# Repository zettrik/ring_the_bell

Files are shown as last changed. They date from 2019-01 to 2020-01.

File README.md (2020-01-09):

# ring_the_bell
*speedy bees*

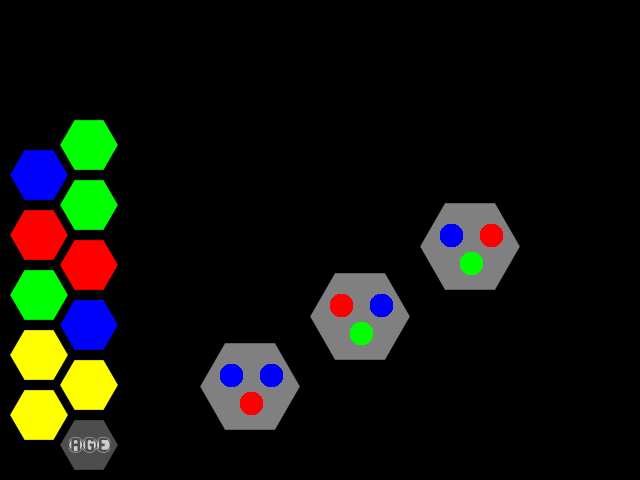
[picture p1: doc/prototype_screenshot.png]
Screenshot Prototype


## Game Principle

### Rules Of "Climb The Ladder"

The goal of this game is to climb the ladder and ring the bell. But
you won't climb alone. You have to be fast as a team.

The "ladder" has ten random blinking lights. Every player has a gamepad with three
blinking buttons. They also change the color at random. In one moment a color will
settle on the ladder as one the gamepads. Press as fast as you can all buttons 
with same color. All of you have to do is hit the right button just in time to 
climb one step up.

If one of you ist too slow, the next round will start at the same level.
If one of you hits a wrong button, you fall one step down.

Start of the game will be easy and you will climp up quickly. As you raise level
your time will shorten. Also some unforseen things might happen at any time.

Will you reach the top and ring the bell?

## User Guide

The Game is a proof of concept and fun project. One focus was to document small
details. Have fun while building it or a similar game.

* [Gamecontrolmaster](/doc/Gamecontrolmaster.md)
* [Display (RGB Lights or Projector)](/doc/Display.md)
* [Gamepads](doc/Gamepads.md)

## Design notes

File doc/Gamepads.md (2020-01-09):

# Gamepads

The Gamepads are self made and consist of a wifi enabled microcontroller (esp32), three buttons and three rgb LEDs. Adopt the .ino firmware file to your needs (like wifi password, IP addresses, etc.) and flash it to the esp32.

* gamepad.ino
  * connects to wifi AP
  * recieves time from local ntp server
  * recieves commands from gamecontrolmaster
    * game states
    * ntp resync
  * animates button colors
  * sends button states to master

Remember you have to recompile the firmware and flash it again on all gamepads after making
changes to your wifi/network setup.

## Gamepad Schematics

Setup: BMS :left_right_arrow: 2x Li-Ion battery 4.2V :left_right_arrow: 5V step up :left_right_arrow: ESP32 dev board :left_right_arrow: 3.3V buttons & LEDs

Wiring of batteries, buttons and LEDs to the ESP32:

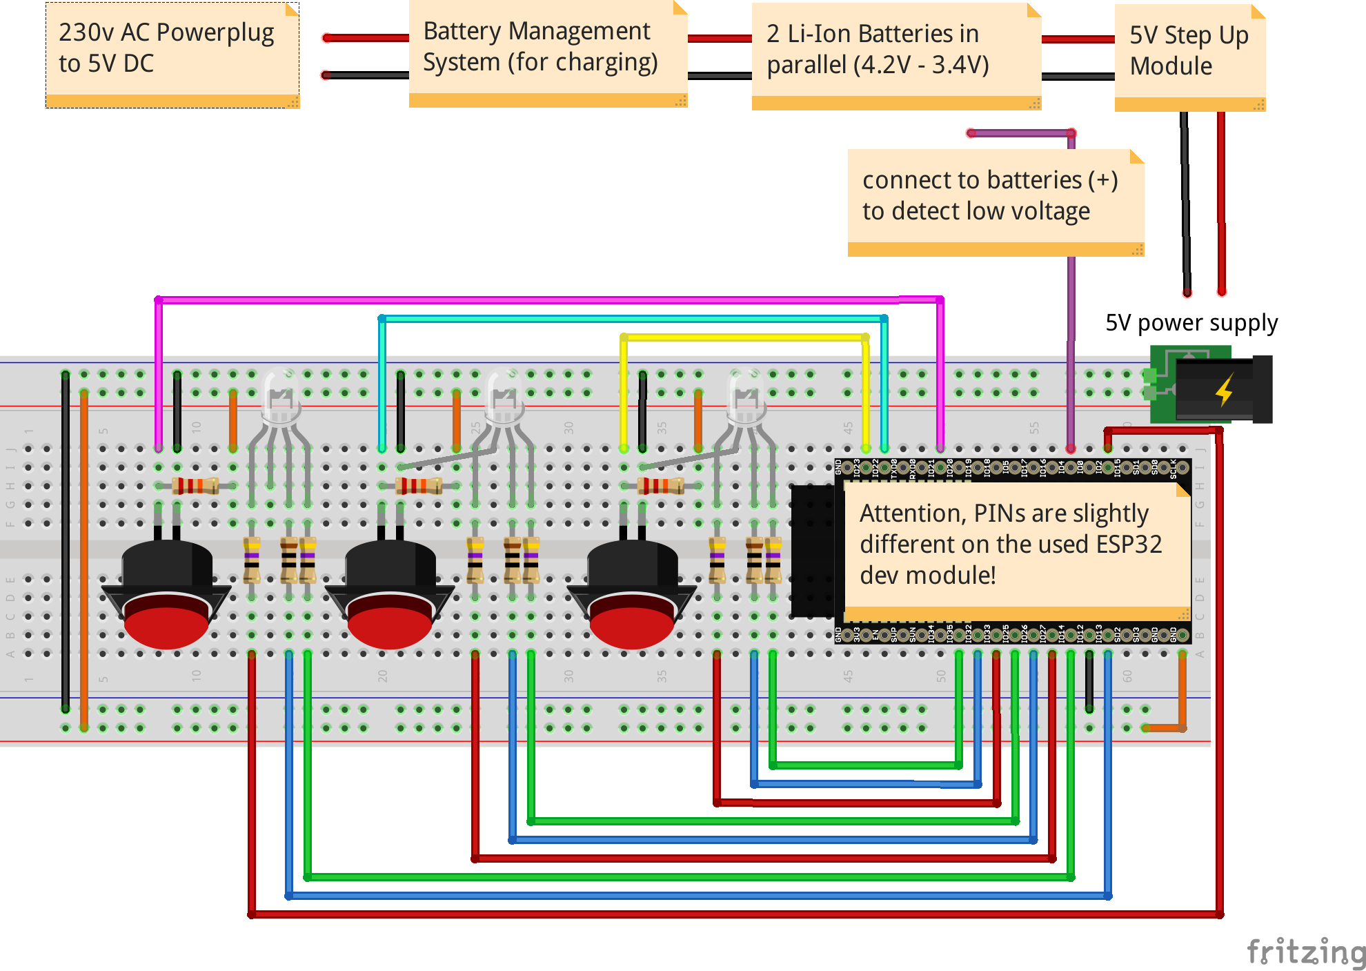
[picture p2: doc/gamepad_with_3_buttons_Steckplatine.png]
gamepad, buttons, leds


Two batteries are used in parallel with 2.200mAh each. The Gamepad uses between 70mA and 200mA. So you should be able to play at least 24h. 8) 
It will blink red and poweroff if battery voltage is below 3.4V. Recharge via USB, powerplug or change the cells. You find many of them in old notebook batteries.

ESP32 Pinmap:

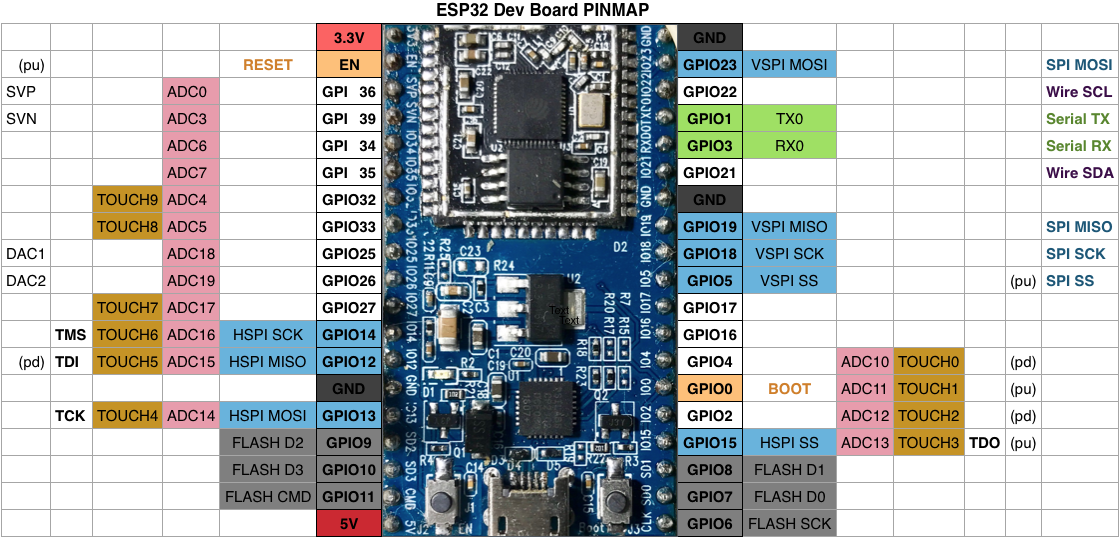
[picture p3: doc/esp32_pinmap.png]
ESP32 Pinmap


* [ESP32 Pin Reference](https://randomnerdtutorials.com/esp32-pinout-reference-gpios/)
* [ESP32 wroom Fritzing part](https://github.com/troelssiggaard/ESP32-fritzing-module)

## Flashing the Firmware

Easiest way of flashing is by using the Arduino IDE. Enhance it with the software from
espressif to flash esp32 boards.

* Install the current upstream Arduino IDE at the 1.8 level or later. The current version is at the [Arduino website](http://www.arduino.cc/en/main/software).
* Start Arduino and open Preferences window.
* Enter ```https://dl.espressif.com/dl/package_esp32_index.json``` into *Additional Board Manager URLs* field. You can add multiple URLs, separating them with commas.
* Open Boards Manager from Tools > Board menu and install *esp32* platform.
* Select your ESP32 board from Tools > Board menu after installation (in our case "NodeMCU-32S").

* [Espressif Esp32 @ github](https://github.com/espressif/arduino-esp32)

## Gamepad States

To lower complexity the gamepad software is written as a state machine. See
https://www.norwegiancreations.com/2017/03/state-machines-and-arduino-implementation/
for a quick introduction.

* states:
  * [1] random blinking
  * [2] freeze
  * [3] send udp packet
  * [4] recieve udp packet
  * [5] blink buttons pressed right in time
  * [6] sync time
* inputs:
  * udp packets
* outputs:
  * LEDs
  * udp packets

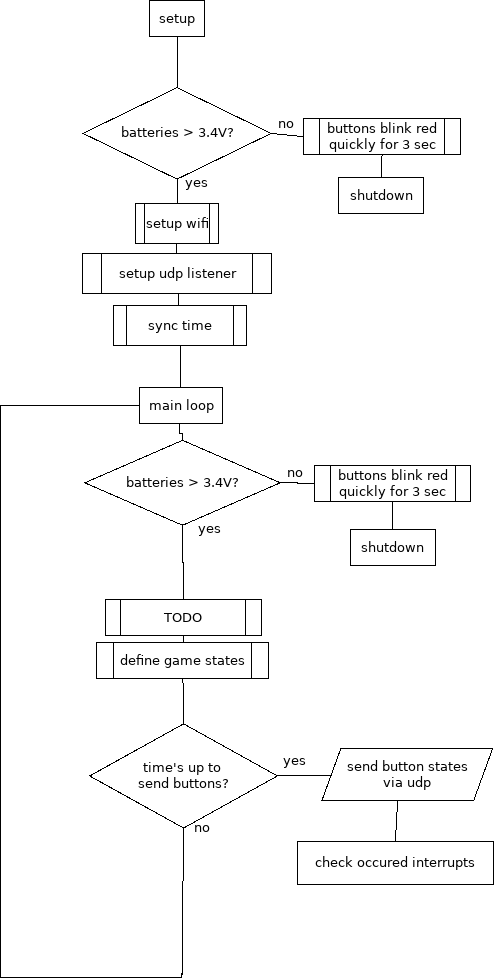
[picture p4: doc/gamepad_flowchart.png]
Gamepad flowchart


### UDP Packets
* timestamp, button1, color, dt, button2, color, dt, button3, color, dt
 * dt means after how many ms button was last pressed in this second
 * e.g.: "1546727493, 1,1,0, 2,3,427, 3,1,755"
* debug with any linux computer in the same wifi with: `sudo tcpdump -vvv -l -n port 3333`
* modus can be:
  * 0: nothing
  * 1: Helo
  * 2: Freeze
  * 3: Release
  * 4: NTP resync
  * 5: Animation1
  * 6: Animation2

## Open Hardware Power Supply
There are plenty of cheap commercial modules available. One is used for the prototype. You could go the full open hardware path by replacing them. Here are some ideas:

* li-ion battery management system
  * https://easyeda.com/search?wd=li-ion%20bms
  * https://github.com/stuartpittaway/diyBMS
  * https://secondlifestorage.com/index.php
  * https://www.youtube.com/watch?v=OdH3wYeFJ3M
  * https://foxbms.org
  * https://github.com/Teslafly/OpenBMS

* 5V step up boost module
  * https://chioszrobots.com/2013/10/11/dc-dc-1a-3v-to-5v-converter-step-up-boost-module/
  * https://easyeda.com/oshw/Arduino_Pro_Mini_328_5V_16MHz_Open_hardware-PuigQOLlx

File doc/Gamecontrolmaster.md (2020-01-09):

# Gamecontrolmaster

## Pyglet Prototype

There is a software prototype of the game for easier development, testing
the rules and joy of gameplay.

Screenshot Prototype

It uses pyglet as game engine. Most software the protoype depends on is in the
Debian Linux distribution. The newest version of pyglet comes via pip. Install
with the following commands.
```
cd prototype
apt install python3-pip freeglut3-dev python3-serial
pip3 install -r requirements.txt
python3 prototype.py
```

### Start on Boot
* create /lib/systemd/system/prototype.service with:
```
[Unit]
Description=Prototype
After=multi-user.target

[Service]
WorkingDirectory=/home/pi/ring_the_bell/prototype/
ExecStart=/usr/bin/python3 prototype.py

[Install]
WantedBy=multi-user.target
```
* chmod 644 /lib/systemd/system/prototype.service
* systemctl daemon-reload
* systemctl enable prototype.service

### Keybindings (Pre State Machine)

There is only a limited number of differnent states in the game. Test them in
the prototype with the letters in the brackets.
* [s] start
* [t] request gamepads to resync their time (ntp)
* [r] random blinking
* [f] freeze, wait for reactions
* [e] release
* [u] level up
* [d] level down
* [w] win
* [q] quit

## Raspberry Pi With Raspbian (Debian Stretch)

* Install [Raspbian](https://www.raspberrypi.org/downloads/raspbian/)
* You will need these essential Debian packages for gamecontrolmaster:
  * `python3 ntp`
  * Also install python3 from requirements.txt.
* There is no standalone mode yet. Use the gamemaster headless via ssh, in addition with the following handy packages:
  * `git` - to get the software
  * `screen` - for disruptable ssh sessions
  * `htop` - resource monitoring
  * `mc` - commandline file manager
  * `tcpdump` - debug network traffic
  * `vim` - file editor
* For all features install a dekstop like fluxbox
  * `lightdm fluxbox lxterminal bbrun`

## Components

### Wifi In AP Mode

* [Raspberry Pi help on this](https://www.raspberrypi.org/documentation/configuration/wireless/access-point.md)
* name: "speedybees"
* password: "rockyoursocksoff"
* IP address: 172.16.2.2
* or set up a separate access point instead of the onboard chip
  * switch wifi to client mode on Pi
  * leave IP address of Rapsberry Pi: 172.16.2.2
  * set IP address of access point: 172.16.2.1
  * use same wifi name + credentials or recompile firmware for gamepads
  * enable DHCP server on access point for address range: 172.16.2.3 - 172.16.2.254
  * no internet connection or DNS is needed but it will nat an existing one

### NTP

* ntp server - add this line to /etc/ntp.conf:
  * restrict 172.16.2.0 mask 255.255.255.0 nomodify notrap

### Firewall

* open firewall ports:
  * 123 for ntp
  * 3333 for ingame udp server

### non-root USB

* allow non-root users access to the USB interface:
  * adduser <your_pi_user> dialout

### prototype.py

* start prototype.py
  * starts UDP server in separate thread
  * shows game state on screen
  * send UDP packets with game state
  * recieves UDP packets with buttons states from pads

## Troubleshooting

In case you're building this setup the first time or you have trouble with some
components here are some debugging hints:

* take a look at /var/log/daemon.log for connected gamepads (and other clients)
* see ntp requests (changed timestamps) with: tcpdump -i wlan0 -v -n port 123
* see udp packets (transmitted game signals) with: tcpdump -i wlan0 -n port 3333
  * -tt for unix timestamp
  * -X for ASCII content of packets
* test basic DMX signals with: python3 prototype/libs/dmx.py
  * or: apt install ola
  * and try ola_dmxmonitor and ola_dmxconsole

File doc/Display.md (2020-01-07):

# Display

## Projector + 10x Canvas 

The quick and cheap way...
* build ten white canvases in hexagonal comb form
* use projector and mapping tool
* connect projector to Pi HDMI 

## Tri LED Show Bar, DMX controlled

Use standard hardware for theaters and clubs, allows better scaling and reuseable elements.
Lights are connected to each other and to the controller with XLR cable/plugs in series. [DMX Basics](http://www.lutron.com/en-US/education-training/Documents/dmx%20webinar_7-29-2010.pdf)

Setup: power plug :arrow_left: USB :arrow_right: Raspberry Pi :arrow_left: USB :arrow_right: USB-DMX controller :arrow_left: XLR :arrow_right: RGB Lights

### A) Light Bars
compact, costs around 200-400€

* https://www.thomann.de/de/stairville_show_bar_triled_18x3wb_stock.htm
* https://www.ebay.de/itm/Showtec-Cameleon-Bar-12-3-IP65-LED-12x-3W-RGB-Light-DMX-Lichtleiste-Outdoor-/201976229900
* https://www.ebay.de/itm/U-king-72W-10PCS-36LED-Par-RGB-Buhnenlicht-DMX-512-Disco-DJ-Wedding-Party-Lichts/292784228642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
* https://www.ebay.de/itm/U-king-10STK-36W-Buhnenlicht-18LED-Par-RGB-Licht-7CH-Channel-Disco-Wedding-Party/292806135256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
* https://www.ebay.de/itm/10stk-RGBW-12LED-Par-Buhnenbeleuchtung-DMX512-Licht-Disco-Party-Lichteffekt-F2Y1/183417140600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
* https://www.ebay.de/itm/24x-3W-RGB-LED-Bar-Wall-Washer-8-Sektionen-DMX-Stage-Scheinwerfer-Lichtleiste/332858111664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

### B) LED Par
10x Pars

* https://www.amazon.de/dp/B07D8MHP9J/ref=psdc_528377031_t1_B07J4TPDG2
* https://www.amazon.de/dp/B07G87HGR8/ref=psdc_528377031_t3_B07J4TPDG2
* https://www.amazon.de/Bühnenbeleuchtung-Latta-Alvor-Lichteffekte-Partybeleuchtung/dp/B07BN9SH4J/

* [Dip Switch Calculator](https://www.chauvetdj.com/chauvet-dj-dip-switch-calculator/)

### DMX Controller
You a need an USB controller for sending DMX signals to the lights.

* USB to DMX adapter
  * Enttec Enttec Open DMX USB (70€)
    * basic USB to DMX converter, lacks microprocessor control, will hiccup if your computer gets stuck
  * Enttec DMX USB Pro MK2, with Linux support (190€)
  * https://www.elektormagazine.de/news/isolierter-usb-dmx512-konverter-1-kv
  * self made adapters: [search e.g. on easyeda.com](https://easyeda.com/search?wd=usb%20dmx)

#### Enttec DMX USB Pro Mk2
* PRO Mk2 comes with a RGB LED indicator located on the top (above the usb connector). The LED will blink between these colours, and each colour signifies the related activity:
  * white: PRO Mk2 is powered on and idle
  * green: DMX1 send or receive (DMX Port 1)
  * yellow: DMX2 send or receive (DMX Port 2)
  * blue: standalone mode (show playback)
  * purple: MIDI in or out
  * red: error or unsupported request

#### DMX Software
* [DmxPy](https://github.com/trevordavies095/DmxPy) - Control USB-DMX Hardware with Python 3. Works with Raspberry Pi and supports Enttec DMX USB Pro.
  * is included in the prototype
* [Open Lighting Architecture](https://www.openlighting.org/) - take a look if you're thinking bigger
* http://www.raspberrypi-dmx.org
* http://www.lightingandsoundamerica.com/mailing/PLASAProtocol/PSummer2015_BuildYourOwnDMXTester.pdf

## DIY Power LED

This is way cheaper than DMX Hardware. You basically need some power LEDs and a
multiplexer. You won't need DMX but will have fun with your own protocol.

* 10x RGB 3W LED
* 3.3V multiplexer 
 * for arduino a 5V would do it: 74HCT245
* some Darlington ULN2003A 
  * 500mA per channel; multi channel possible
  * or use 30x 3.3V n-channel mosfet

* https://learn.adafruit.com/rgb-led-strips/usage
* http://www.tbideas.com/blog/build-an-arduino-shield-to-drive-high-power-rgb-led/

## DIY LED Stripes, Neopixel

Cut stripes in pieces and bring them in form for the combs. Control with
mosfets or darlington + multiplexer (same as with power LEDs).

* https://dordnung.de/raspberrypi-ledstrip/ws2812
* https://diystagedesign.wordpress.com/2014/06/06/rgb-led-strip-panels/
* https://www.instructables.com/id/Driving-RGB-LED-strips-off-an-Arduino/
* https://www.hackerspace-bamberg.de/Dmx2rgb

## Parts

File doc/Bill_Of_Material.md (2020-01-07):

# Bill Of Material

All electronic parts are easy to find in online shops (therefore no links).

The wood was bought as a big board and cut in pieces with a handsaw.

Costs for the lights are high because of professional equipment (the cheapest)
with DMX. That way all components are also usable for other light
installations. You can save a lot of money building the lights yourself (see
DIY RGB LEDs below).

## Gamecontrolmaster 

Number | Name | Sum
------ | ---- | -----
1x | Pi3 with case, sd-card and power supply | 50€
1x | potentiometer for setting difficulty | 1€
1x | speaker |
1x | car horn |
-  | **sum** | **ca. 50€**

## Display

### Variant 1: Light Elements (RGB, DMX)
Number | Name | Sum
------ | ---- | -----
1x | Enttec Open DMX USB | 70€
10x | RGB Par with DMX controller | 400€
10x | XLR cable | 4€
11x | combs from six pieces of wood (12mm x 12mm x 12mm)| 30€
11x | milk glass as front plate for combs (24mm x 24mm) | 70€
11x | wooden back plate for combs (24mm x 24mm) | 50€
-  | **sum** | **ca. 660€**

### Variant 2: Projector and Canvases
Number | Name | Sum
------ | ---- | -----
1x | Projcetor (VGA resolution, HDMI) | 400€
10x | Hexagonal Canvas | ?
-  | **sum** | **ca. 400€**

## Gamepads

These are the parts for one gamepad. The gamedesign is optimised for three
players. But you can easily connect more. The limiting factor will be the
number of wifi connections handled by the Pi. In case you're planning with some
dozens gamepads better use a separated wifi access point.

Number | Name | Sum
------ | ---- | -----
1x | Espressif ESP32 (or similar board) | 7€
1x | li-ion battery management system (BMS) | 1€
1x | 5V step up boost module | 1,50€
1x | battery holding for two 18650 cells (parallel) | 2€
2x | batteries 18650 li-ion (from old notebook) | 0€
1x | flip switch | 1€
3x | arcade buttons | 3,60€
3x | RGB LED (common cathode) for buttons | 0,30€
6x | 47 Ohm resistor | 0,01€
3x | 10 Ohm resistor | 0,01€
3x | 22 kOhm resistor | 0,01€
1x | combs from six pieces of wood (12mm x 12mm x 9mm)| 3€
-  | **sum** | **ca 20€ (each)**

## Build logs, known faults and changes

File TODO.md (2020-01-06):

# TODOs
* [ ] switch from udp packets to mqtt/tcp
* [ ] test vue.js as frontend
 * http://rafaelescala.com/vue-konva/#/
 * with nuxt
* [ ] define game states
  * [ ] implement finite state machine
* [ ] fix firmware errors
  * seems like this would help: https://github.com/espressif/arduino-esp32/issues/393
* [ ] build wooden gamecontrolmaster case
  * [ ] add coin slot and glass bucket
* [ ] setup introduction page; move howto details in separate file
* [ ] describe off-grid powered version for festivals (solar)
* [ ] check licenses
  * open hardware for own schematics (cern license?)
  * dmxpy MIT license
  * schematic files sources ...
* [ ] find cool audio samples
 * http://99sounds.org/
 * https://opengameart.org/
 * http://dig.ccmixter.org/games
 * https://freesound.org/browse/
* [ ] play with esp <-> vga: http://www.fabglib.org/conf_v_g_a.html

# Done
* [x] try MQTT/TCP instead of plain UDP packets and see if performance fits
 * seems more than fast enough, the delay with the broker is under 0.001 seconds
* [x] build tough connections for leds and buttons in gamepad
  * used LEDs are to dark for outdoor usage
* [x] build wooden gamepad case (comb with 13mm edge length and 13mm depth)
* [x] gamepad blockdiagram
* [x] add low voltage disconnect and red warning on gamepads
* [x] debug mysterious dmx behaviour 
 * Enttec USB DMX Pro Mk2 needs 300mA @ 5V supply
 * Pi USB output seems to be not stable enough, also not with USB hub
 * power supply for Pi must be sufficient
* [x] gamepad suggestions for open hardware BMS and 5V step up
* [x] setup wifi in pi server
* [x] clone git to pi server
* [x] build prototype to test gameplay
* [x] gamepad udp send button states (pad no., button no., color, timestamp)
* [x] gamepad recieve game states and change modus (random blinking, waiting, show win/loose...)
* [x] gamepad control button rgb colors
* [x] setup pi server

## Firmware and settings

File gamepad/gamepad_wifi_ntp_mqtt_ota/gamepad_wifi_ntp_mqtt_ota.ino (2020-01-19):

#include <WiFi.h>
#include <EspMQTTClient.h>
#include <time.h>
#include <esp_wifi.h>
//#include <ESPmDNS.h>  // for ota
//#include <WiFiUdp.h>  // for ota
#include <ArduinoOTA.h>  // for ota

/* gamepad info & modes*/
const char *my_name = "gamepad-uno";
const int gamepad_version = 2;
char game_mode = ' ';
unsigned long mode_interval = 1000000; // 1s in µs
unsigned long send_interval = 10000000; // 10s in µs

/* wifi */
//const char *ssid = "speedybees";
//const char *password = "rockyoursocksoff";
const char *ssid = "Bill Hicks";
const char *password = "blum3ngi3ss3n";
IPAddress local_ip(127, 0, 0, 0); // will be set via dhcp
WiFiClient espClient;
unsigned long wifi_connects = 0;
long wifi_signal = 0;

/* mqtt */
EspMQTTClient mqtt_client(
  "WifiSSID",
  "WifiPassword",
  "192.168.1.111",  // MQTT Broker server ip
  "", // mqtt user
  "", // mqtt pw
  "uno" // client name
);
const char *topic_status = "gamepad/dos/status";
const char *topic_in = "gamepad/dos/in";
const char *topic_out = "gamepad/dos/out";
const char *topic_mode = "gamepad/dos/mode";
char msg[15];

/* I/O */
const byte led0 = 5; // on board LED
const byte led_1_r = 32; // G32, red LED on first button
const byte led_1_g = 33; // G23
const byte led_1_b = 25; // G25
const byte led_2_r = 26; // G26
const byte led_2_g = 27; // G27
const byte led_2_b = 14; // G14
const byte led_3_r = 12; // G12
const byte led_3_g = 13; // G13
const byte led_3_b = 4;  // G4, blue LED on third button
const byte button1 = 36; // first input button
const byte button2 = 39;
const byte button3 = 34;
const byte touch1 = 15; // Touch Sensor 3 at G15
const byte bat_sensor = 2; // G2, connect to batterie (+)
byte button1_state = 0;
byte button2_state = 0;
byte button3_state = 0;
byte button1_pressed = 0;
byte button2_pressed = 0;
byte button3_pressed = 0;
unsigned long button1_presstime = 0;
unsigned long button2_presstime = 0;
unsigned long button3_presstime = 0;
int touch_value1 = 0;

/* ntp */
const char *ntpServer = "1.debian.pool.ntp.org";
//const char *ntpServer = "172.16.2.2";
const unsigned long check_ntp_interval = 36000000;
const long  gmtOffset_sec = 3600;
const int   daylightOffset_sec = 3600;
unsigned long now = 0;
unsigned long before = 0;
unsigned long interval_before = 0;
unsigned long rtc_now;
unsigned long time_delta;
unsigned long ntp_last_check;
time_t unixseconds;
struct timeval thistime;

/* buttons leds */
//long random;


void setup() {
  Serial.begin(115200);
  Serial.println("===");
  Serial.print("my name is: ");
  Serial.println(my_name);
  Serial.print("version: ");
  Serial.println(gamepad_version);
  Serial.println("---");
  setCpuFrequencyMhz(240);
  pinMode(led0, OUTPUT);
  digitalWrite(led0, 0);
  pinMode(led_1_r, OUTPUT);
  pinMode(led_1_g, OUTPUT);
  pinMode(led_1_b, OUTPUT);
  pinMode(led_2_r, OUTPUT);
  pinMode(led_2_g, OUTPUT);
  pinMode(led_2_b, OUTPUT);
  pinMode(led_3_r, OUTPUT);
  pinMode(led_3_g, OUTPUT);
  pinMode(led_3_b, OUTPUT);
  pinMode(button1, INPUT_PULLDOWN);
  pinMode(button3, INPUT_PULLDOWN);
  pinMode(button2, INPUT_PULLDOWN);
  pinMode(bat_sensor, INPUT_PULLDOWN);

  check_battery();    
   
  // initialize random number generator
  randomSeed(analogRead(0));

  // system starting, all buttons blue
  buttons_all_blue();
  setup_wifi();
  setup_mqtt();
  get_ntp_time();
  
  
  // let all button leds blink so gamer sees everything is working
  //buttons_rotation();
  buttons_single_color();
  buttons_flash();
  // system is up, green leds for 3 sec
  buttons_all_green();
  delay(1000);
  buttons_all_off();

  // prepare firmware updates over the air
  // keep the firewall on your arduino dev pc open
  setup_ota();
}

void loop() {
  ArduinoOTA.handle(); // listening for new firmwares
  check_battery();
  gettimeofday(&thistime, NULL);
  now = (thistime.tv_sec * 1000000 + thistime.tv_usec);
  //now = system_get_time();
  read_buttons();
  
  read_touchsensors();
  mqtt_client.loop();

  /* regular status reports */
  if ((before + send_interval) <= now) {
    check_wifi_signal();
    mqtt_client.publish(topic_status, String(wifi_signal));
    read_touchsensors();
    mqtt_client.publish(topic_status, String(touch_value1));
    before = now;
    send_button_times();
    reset_buttons();
  }
  
  /* game modes */
  if ((interval_before + mode_interval) < now) {
    if (game_mode == 'r') {
      Serial.println("in random mode");
      mode_random();
    }
    else if (game_mode == 'f') {
      Serial.println("in freeze mode");
      mqtt_client.publish(topic_mode, "f");
      mode_freeze();
    }
    else {
      //buttons_rotation();
      //print_local_time();
    }
    Serial.print("now: ");
    Serial.println(now);
    interval_before = now;
  }
}

/*
 * read touch sensors
 */
void read_touchsensors() {
  touch_value1 = touchRead(touch1);
  //Serial.print("touch: ");
  //Serial.println(touch_value1);
}

/*
 * read actual state of buttons
 */
void read_buttons() {
  button1_state = digitalRead(button1);
  button2_state = digitalRead(button2);
  button3_state = digitalRead(button3);
  // save the first time a button was pressed in this interval
  if ((button1_state == 1) && (button1_pressed == 0)) {
    button1_pressed = 1;
    button1_presstime = now - before;
  }
  if ((button2_state == 1) && (button2_pressed == 0)) {
    button2_pressed = 1;
    button2_presstime = now - before;
  }
  if ((button3_state == 1) && (button3_pressed == 0)) {
    button3_pressed = 1;
    button3_presstime = now - before;
  }
}

/*
 * send button states via mqtt
 */
void send_button_times() {
  digitalWrite(led_1_r, 1);
  sprintf(msg,"%16lu", button1_presstime);
  
  // some debug infos...
  Serial.println("press times in micro seconds (b1, b2, b3)");
  Serial.print(button1_presstime);
  Serial.print(", ");
  Serial.print(button2_presstime);
  Serial.print(", ");
  Serial.println(button3_presstime);
  time(&unixseconds);
  Serial.print("unixseconds: ");
  Serial.println(unixseconds);
  Serial.print("uptime: ");
  Serial.println(now);
  
  mqtt_client.publish(topic_out, "b1");
}

void reset_buttons() {
  button1_pressed = 0;
  button2_pressed = 0;
  button3_pressed = 0;
  button1_presstime = 0;
  button2_presstime = 0;
  button3_presstime = 0;
  digitalWrite(led_1_r, 0);
}

/*
 * low voltage shutdown
 */
void check_battery() { 
  if (digitalRead(bat_sensor) < 600) {
    buttons_all_red();
    //delay(3000);
    //shutdown();
  }
}

void shutdown() {
  Serial.println("Low voltage shutoff is not yet implemented.");
}

/*
 * wifi
 */
void setup_wifi() {
  WiFi.softAPdisconnect(true);
  WiFi.disconnect(true);
  WiFi.persistent(false); //  every wifi.begin() writes to flash, this stops it
  WiFi.mode(WIFI_STA);
  WiFi.begin(ssid, password);
  Serial.println("Starting wifi connection");
  // Try max. 20 seconds to connect to access point.
  //while(WiFi.status() != WL_CONNECTED) {
  for (int i = 0; i <= 79; i++) {
    // blink slowly while connecting
    digitalWrite(led0, 0);
    delay(250);
    digitalWrite(led0, 1);
    delay(125);
    digitalWrite(led0, 0);
    Serial.print(".");
    if (WiFi.status() == WL_CONNECTED) {
      i = 80;
      wifi_connects += 1;
    }
  }
  Serial.println("");
  Serial.print("Connected to ");
  Serial.println(ssid);
  Serial.print("IP address: ");
  local_ip = WiFi.localIP();
  Serial.println(local_ip);
  for (int i = 0; i < 10; i++) {
    // blink fast when successful
    digitalWrite(led0, 0);
    delay(25);
    digitalWrite(led0, 1);
    delay(25);
  }
}

/*
 * wifi signal strength
 */
void check_wifi_signal(){
  wifi_signal = 0;
  for (int i = 0; i < 5; i++){
    wifi_signal += WiFi.RSSI();
    delay(20);
  }
  wifi_signal = wifi_signal / 5;
  //Serial.print("wifi signal strength: ");
  //Serial.println(wifi_signal);
}

/*
 * mqtt
 */
void setup_mqtt() {
  mqtt_client.enableDebuggingMessages();
}
// This function is called once everything is connected (Wifi and MQTT)
// WARNING : YOU MUST IMPLEMENT IT IF YOU USE EspMQTTClient
void onConnectionEstablished()
{
  // Subscribe to topic and display received message to Serial
  mqtt_client.subscribe(topic_in, [](const String & payload) {
    Serial.print("mqtt recieved at unixseconds: ");
    Serial.println(unixseconds);
    Serial.print("  now: ");
    Serial.println(now);
    Serial.print("mqtt message: ");
    Serial.println(payload);
    if ( payload == "t") {
      mqtt_client.publish(topic_mode, String('t'));
      mqtt_client.publish(topic_out, String(unixseconds));
      mqtt_client.publish(topic_out, String(now));
      get_ntp_time();
    }
    if ( payload == "r") {
      mqtt_client.publish(topic_mode, String('r'));
      mode_random();
    }
    if ( payload == "f") {
      mqtt_client.publish(topic_mode, String('f'));
      mqtt_client.publish(topic_out, String(unixseconds));
      mqtt_client.publish(topic_out, String(now));
      mode_freeze();
    }
    
    mqtt_client.publish(topic_out, String(payload));
  });

  // Publish a message to topic
  //mqtt_client.publish("test/foo", "hooooray"); // You can activate the retain flag by setting the third parameter to true
  // Execute delayed instructions
  //mqtt_client.executeDelayed(5 * 1000, []() {
    //mqtt_client.publish("test/foo", "5 seconds later");
  //});
}

/*
 * flash firmware over the air
 */
void setup_ota() {
  // Port defaults to 3232
  //ArduinoOTA.setPort(3232);
  // Hostname defaults to esp3232-[MAC]
  ArduinoOTA.setHostname(my_name);
  // No authentication by default
  //ArduinoOTA.setPassword("admin");
  // Password can be set with it's md5 value as well
  // MD5(admin) = 21232f297a57a5a743894a0e4a801fc3
  //ArduinoOTA.setPasswordHash("21232f297a57a5a743894a0e4a801fc3");

  ArduinoOTA.onStart([]() {
      String type;
      if (ArduinoOTA.getCommand() == U_FLASH)
        type = "sketch";
      else // U_SPIFFS
        type = "filesystem";
      // NOTE: if updating SPIFFS this would be the place to unmount SPIFFS using SPIFFS.end()
      Serial.println("Start updating " + type);
    });
  ArduinoOTA.onEnd([]() {
      Serial.println("\nEnd");
    });
  ArduinoOTA.onProgress([](unsigned int progress, unsigned int total) {
      Serial.printf("Progress: %u%%\r", (progress / (total / 100)));
    });
    .onError([](ota_error_t error) {
      Serial.printf("Error[%u]: ", error);
      if (error == OTA_AUTH_ERROR) Serial.println("Auth Failed");
      else if (error == OTA_BEGIN_ERROR) Serial.println("Begin Failed");
      else if (error == OTA_CONNECT_ERROR) Serial.println("Connect Failed");
      else if (error == OTA_RECEIVE_ERROR) Serial.println("Receive Failed");
      else if (error == OTA_END_ERROR) Serial.println("End Failed");
    });
  ArduinoOTA.begin();
}

/*
 * ntp
 */
void get_ntp_time() {
  Serial.println("Fetching time via ntp...");
  configTime(gmtOffset_sec, daylightOffset_sec, ntpServer);
  print_local_time();
}

void check_ntp_time() {
  if (now - ntp_last_check >= check_ntp_interval) {
    get_ntp_time();
    ntp_last_check = now;
    print_local_time();
  }
}
          
void print_local_time() {
  struct tm timeinfo;
  if(!getLocalTime(&timeinfo)){
    Serial.println("Failed to obtain time");
    return;
  }
  Serial.print("local time: ");
  Serial.println(&timeinfo, "%Y-%m-%d %H:%M:%S");
}

/*
 * buttons blinking in action
 */
void buttons_rotation() {
  for (int i = 0; i <= 4; i++) {
    set_buttons(1,0,0,0,1,0,0,0,1);
    delay(333);
    buttons_all_off();
    delay(50);
    set_buttons(0,1,0,0,0,1,1,0,0);
    delay(333);
    buttons_all_off();
    delay(50);
    set_buttons(0,0,1,1,0,0,0,1,0);
    delay(333);
    buttons_all_off();
    delay(50);
  }
  set_buttons(0,0,0,0,0,0,0,0,0);
}

void buttons_single_color() {
  for (int i = 0; i <= 4; i++) {
    buttons_all_red();
    delay(333);
    buttons_all_off();
    delay(100);
    buttons_all_green();
    delay(333);
    buttons_all_off();
    delay(100);
    buttons_all_blue();
    delay(333);
    buttons_all_off();
    delay(100);
  }
}

void buttons_all_red() {
  set_buttons(1,0,0,1,0,0,1,0,0);
}

void buttons_all_green() {
  set_buttons(0,1,0,0,1,0,0,1,0); 
}

void buttons_all_blue() {
  set_buttons(0,0,1,0,0,1,0,0,1);
}

void buttons_all_off() {
  set_buttons(0,0,0,0,0,0,0,0,0);
}

void buttons_all_on() {
  set_buttons(1,1,1,1,1,1,1,1,1);
}

void buttons_flash() {
  for (int i = 0; i <= 8; i++) {
    buttons_all_on();
    delay(150);
    buttons_all_off();
    delay(150);
  }
}

void mode_random() {
  game_mode = 'r';
  buttons_random_rgb();
}

void mode_freeze() {
  game_mode = 'f';
  for (int i = 0; i <= 5; i++) {
    buttons_random_rgb();
    delay(500);
  }
  buttons_random_rgb();
  /* TODO
  save_timestamp();
  read buttons press times
  submit via mqtt
  */
  game_mode = ' ';
}

void buttons_random_rgb() {
  set_buttons( random(1, 3), random(1, 3), random(1, 3),
    random(1, 3), random(1, 3), random(1, 3),
    random(1, 3), random(1, 3), random(1, 3)
  );
}

void set_buttons(int l1r, int l1g, int l1b, int l2r, int l2g, int l2b, int l3r, int l3g, int l3b){
    digitalWrite(led_1_r, l1r);
    digitalWrite(led_1_g, l1g);
    digitalWrite(led_1_b, l1b);
    digitalWrite(led_2_r, l2r);
    digitalWrite(led_2_g, l2g);
    digitalWrite(led_2_b, l2b);
    digitalWrite(led_3_r, l3r);
    digitalWrite(led_3_g, l3g);
    digitalWrite(led_3_b, l3b);
}

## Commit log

2018-12-27 basic prototype with basic graphics
2018-12-27 basic prototype is working with multi players, game has a description
2018-12-30 classlesser code; gamepad schematics; gamepad firmware started
    [gamepad_with_3_buttons.fzz]
2019-01-14 3 led pars
2019-01-14 three buttons
    [gamepad_with_3_buttons.fzz]
2019-01-17 added rgb leds on gamepad
    [gamepad_with_3_buttons.fzz]
2019-01-17 correct power supply
    [gamepad_with_3_buttons.fzz]
2019-01-20 started low voltage protection for gamepads
    [low_voltage_batteries_protection.fzz]
2019-01-28 power to da dmx controller
2019-01-30 low voltage disconnect; gamepad flowchart
    [digispark_low_voltage_disconnect.fzz, low_voltage_batteries_protection.fzz]
2019-01-30 simplified LVD
    [digispark_low_voltage_disconnect.fzz, gamepad_with_3_buttons.fzz]
2019-02-07 gamepad blockdiagram
    [gamepad_with_3_buttons.fzz]
